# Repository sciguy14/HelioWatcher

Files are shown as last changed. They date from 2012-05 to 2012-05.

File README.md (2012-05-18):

HelioWatcher
============

The HelioWatcher is a Sun-Tracking Solar Analytics System developed by Jason Wright &amp; Jeremy Blum.
Learn more at www.heliowatcher.com

3D Prints
---------
Many of the mechanical parts for Actuating the HelioWatcher were 3D-Printed on a MakerBot Replicator.  In this folder, you will find all the design files (sketchup), STLs, and Replicator Dual G-Code Files.  You can also find them on the HelioWatcher Thingiverse Page: http://www.thingiverse.com/thing:22423

Code
----
This is the embedded code that runs on the ATmega-based MightyBoard MotherBoard that controls the HelioWatcher.  It was written in C using AVR Studio.

Datasheets
----------
These are Datasheets for the various electronic modules used in the HelioWatcher.

GRAPHING AND COLLECTION
-----------------------
These are scripts for performing automatic data acquisition from the Solar Panel

HelioWatcher Circuit
--------------------
These are the System-Level Circuit Diagrams from the HelioWatcher

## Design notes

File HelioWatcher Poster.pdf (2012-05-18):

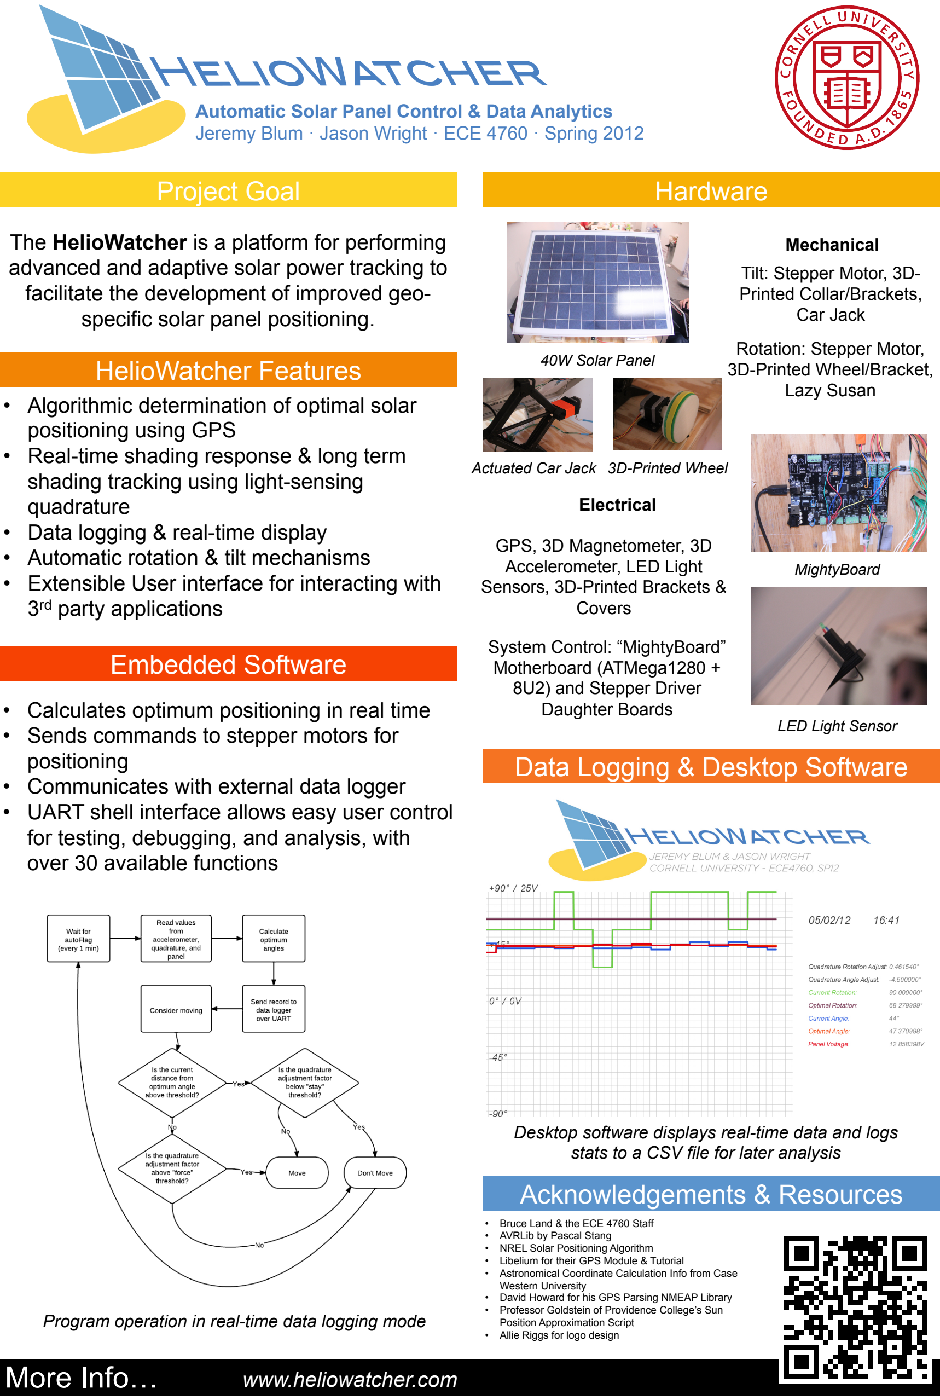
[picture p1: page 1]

### HelioWatcher Features

### Hardware

### Data Logging & Desktop Software

### Project Goal

### Acknowledgements & Resources

- Bruce Land & the ECE 4760 Staff
- AVRLib by Pascal Stang
- NREL Solar Positioning Algorithm
- Libelium for their GPS Module & Tutorial
- Astronomical Coordinate Calculation Info from Case Western University
- David Howard for his GPS Parsing NMEAP Library
- Professor Goldstein of Providence College’s Sun Position Approximation Script
- Allie Riggs for logo design

### Embedded Software

The HelioWatcher is a platform for performing advanced and adaptive solar power tracking to facilitate the development of improved geospecific solar panel positioning.

More Info… | www.heliowatcher.com

Automatic Solar Panel Control & Data Analytics Jeremy Blum · Jason Wright · ECE 4760 · Spring 2012

- Algorithmic determination of optimal solar positioning using GPS
- Real-time shading response & long term shading tracking using light-sensing quadrature
- Data logging & real-time display
- Automatic rotation & tilt mechanisms
- Extensible User interface for interacting with 3rd party applications

Mechanical

Electrical

Rotation: Stepper Motor,
3D-Printed Wheel/Bracket,
Lazy Susan

Tilt: Stepper Motor, 3D-Printed Collar/Brackets,
Car Jack

GPS, 3D Magnetometer, 3D
Accelerometer, LED Light
Sensors, 3D-Printed Brackets & Covers

System Control: “MightyBoard” Motherboard (ATMega1280 +
8U2) and Stepper Driver
Daughter Boards

40W Solar Panel

Desktop software displays real-time data and logs stats to a CSV file for later analysis

Actuated Car Jack 3D-Printed Wheel

MightyBoard

LED Light Sensor

- Calculates optimum positioning in real time
- Sends commands to stepper motors for positioning
- Communicates with external data logger
- UART shell interface allows easy user control for testing, debugging, and analysis, with over 30 available functions

Program operation in real-time data logging mode

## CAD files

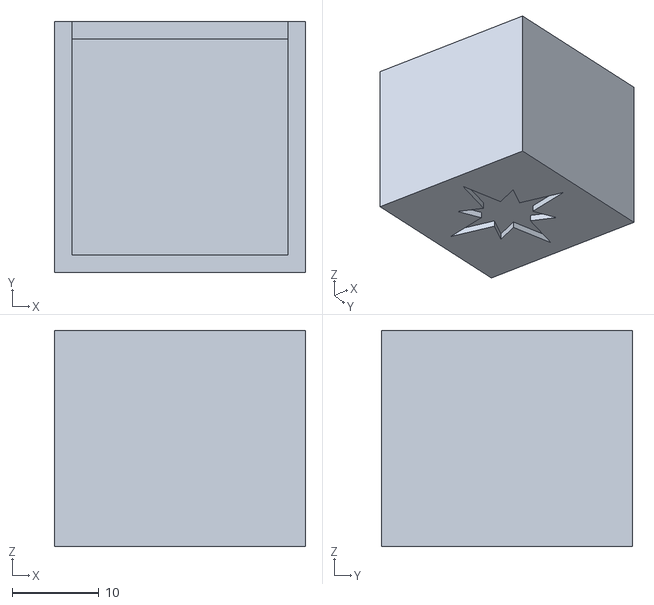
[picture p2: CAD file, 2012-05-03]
3D Prints/covers/mag_cover.stl
29.0 x 29.0 x 25.0

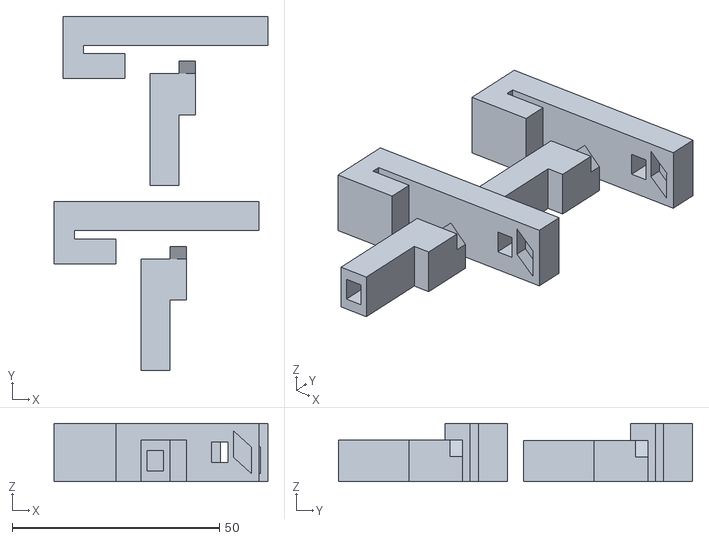
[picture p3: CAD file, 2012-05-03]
3D Prints/quadrature clips/clipTB.stl
51.6 x 85.5 x 14.1

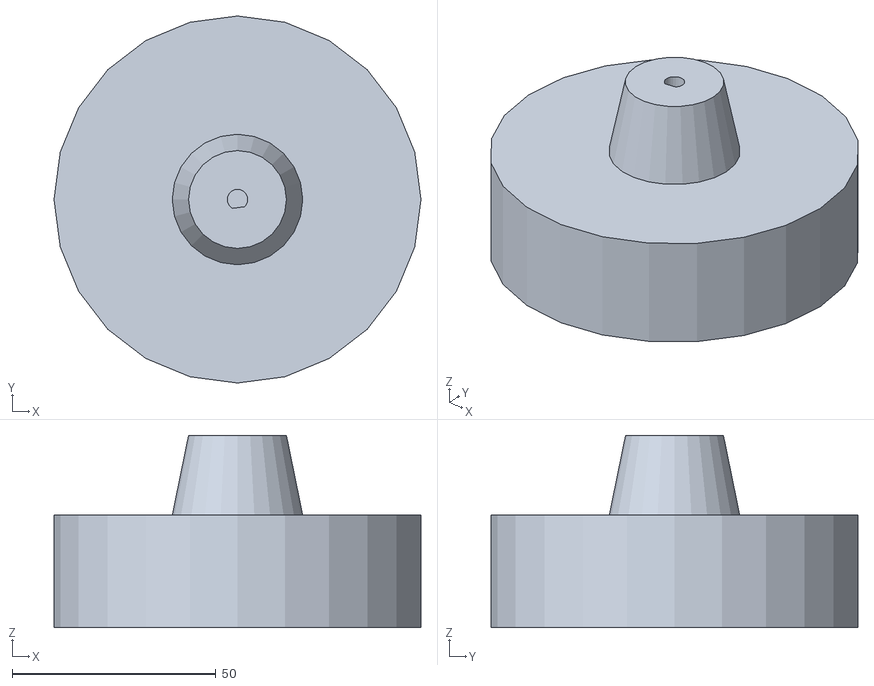
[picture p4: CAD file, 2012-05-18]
3D Prints/rotate/wheel.stl
90.0 x 90.0 x 47.2

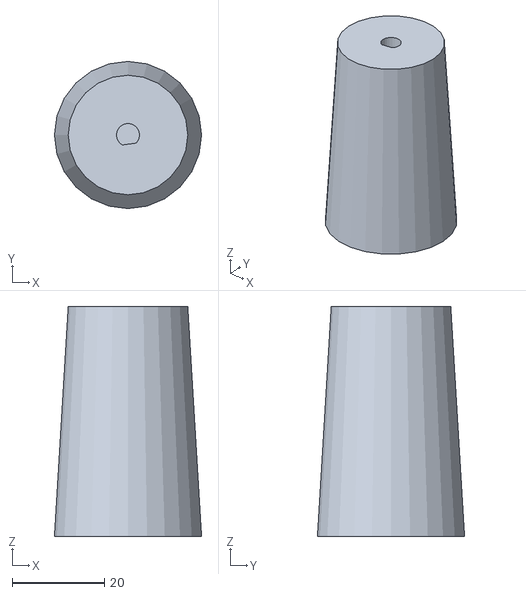
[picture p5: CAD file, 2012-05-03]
3D Prints/stepper jack bracket/collar.stl
32.0 x 32.0 x 50.0

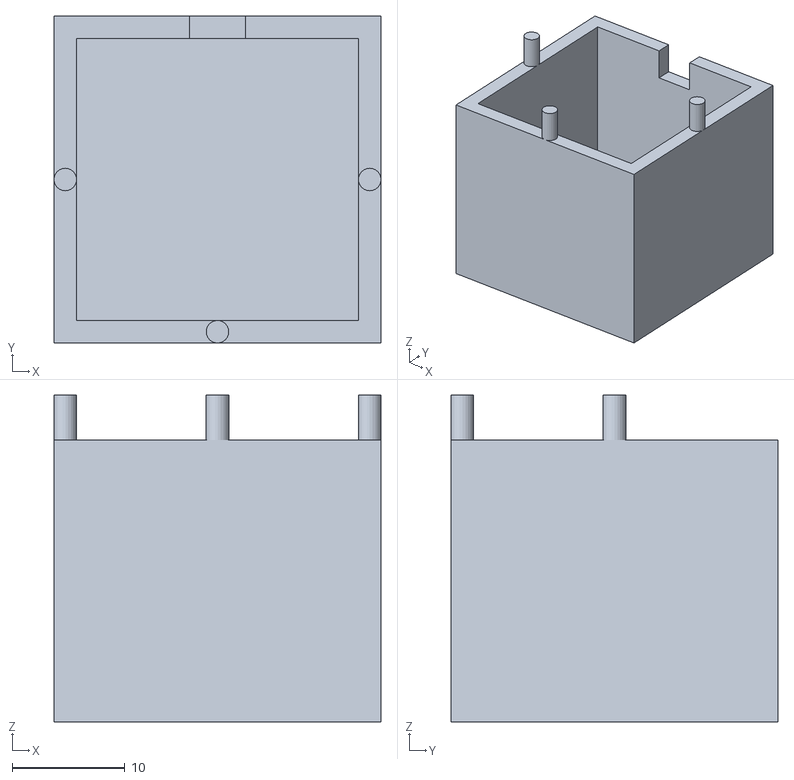
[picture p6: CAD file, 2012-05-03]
3D Prints/covers/ant_cover.stl
29.0 x 29.0 x 29.0

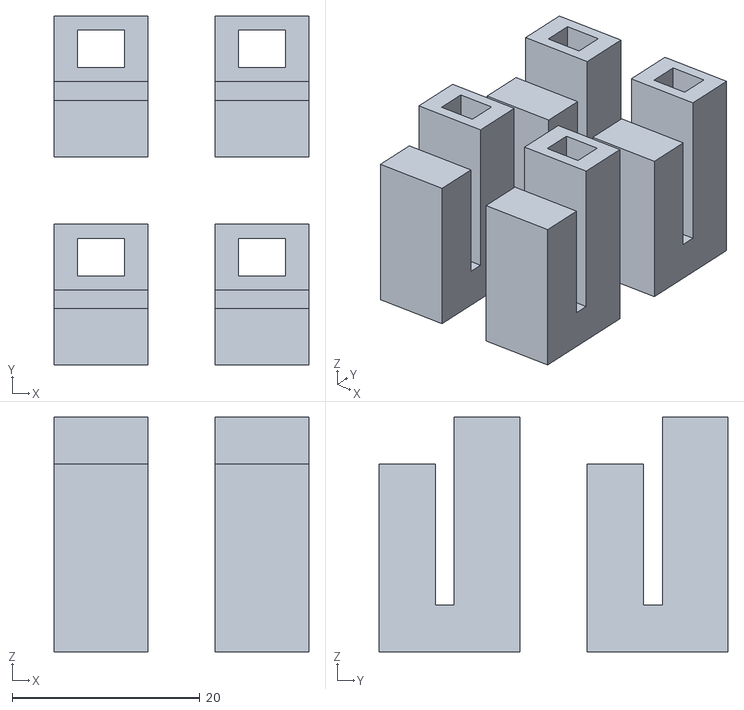
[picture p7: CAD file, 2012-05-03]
3D Prints/quadrature clips/clipLR.stl
27.2 x 37.2 x 25.0

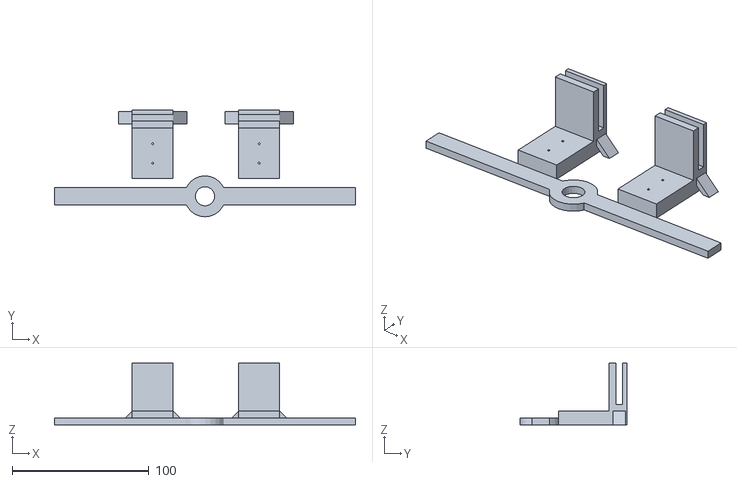
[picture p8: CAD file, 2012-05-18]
3D Prints/rotate/axis-holder.stl
220.0 x 77.9 x 45.0

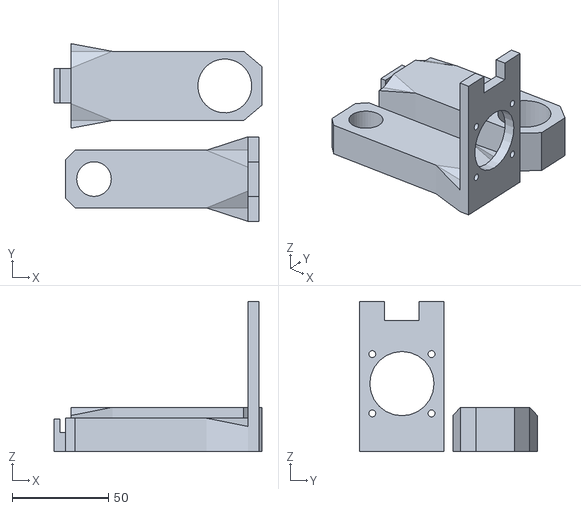
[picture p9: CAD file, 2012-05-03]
3D Prints/stepper jack bracket/jack_bracket.stl
108.2 x 92.5 x 78.2

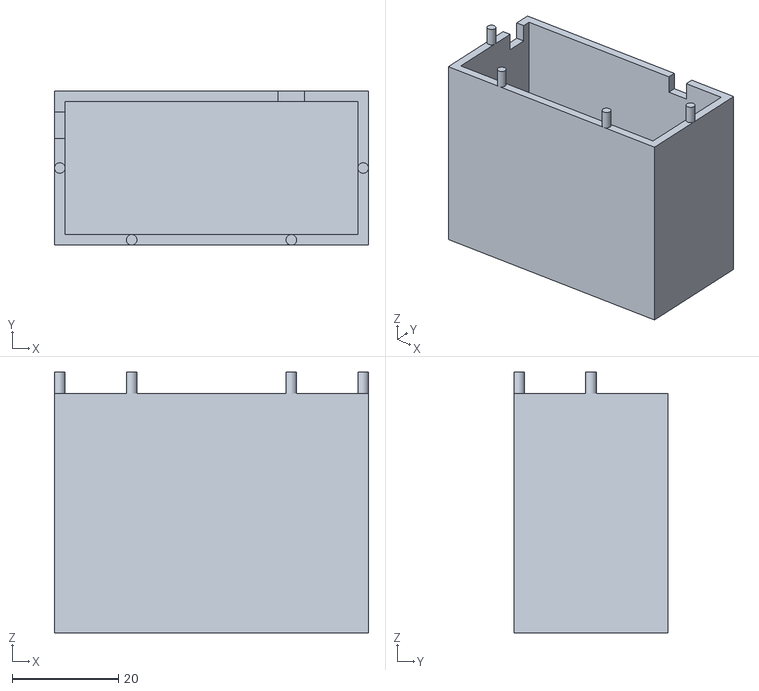
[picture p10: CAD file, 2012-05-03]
3D Prints/covers/gps-cover.stl
59.0 x 29.0 x 49.0

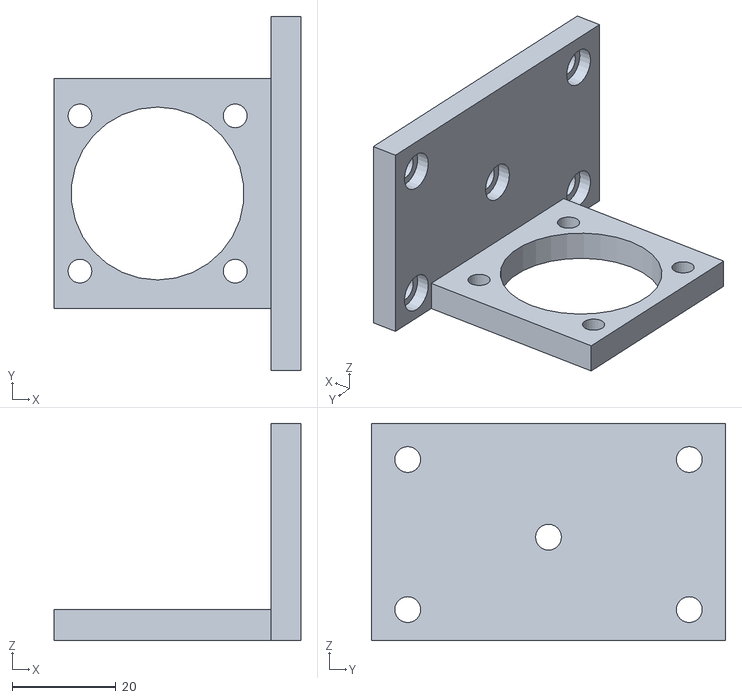
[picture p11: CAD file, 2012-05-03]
3D Prints/rotate/wheel_bracket.stl
47.7 x 68.4 x 42.0

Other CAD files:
3D Prints/covers/ant_cover.skp
3D Prints/covers/gps-cover.skp
3D Prints/covers/mag_cover.skp
3D Prints/quadrature clips/clipLR.skp
3D Prints/quadrature clips/clipTB.skp
3D Prints/rotate/axis-holder.skp
3D Prints/rotate/wheel.skp
3D Prints/rotate/wheel_bracket.skp
3D Prints/stepper jack bracket/collar.skp
3D Prints/stepper jack bracket/jack_bracket.skp

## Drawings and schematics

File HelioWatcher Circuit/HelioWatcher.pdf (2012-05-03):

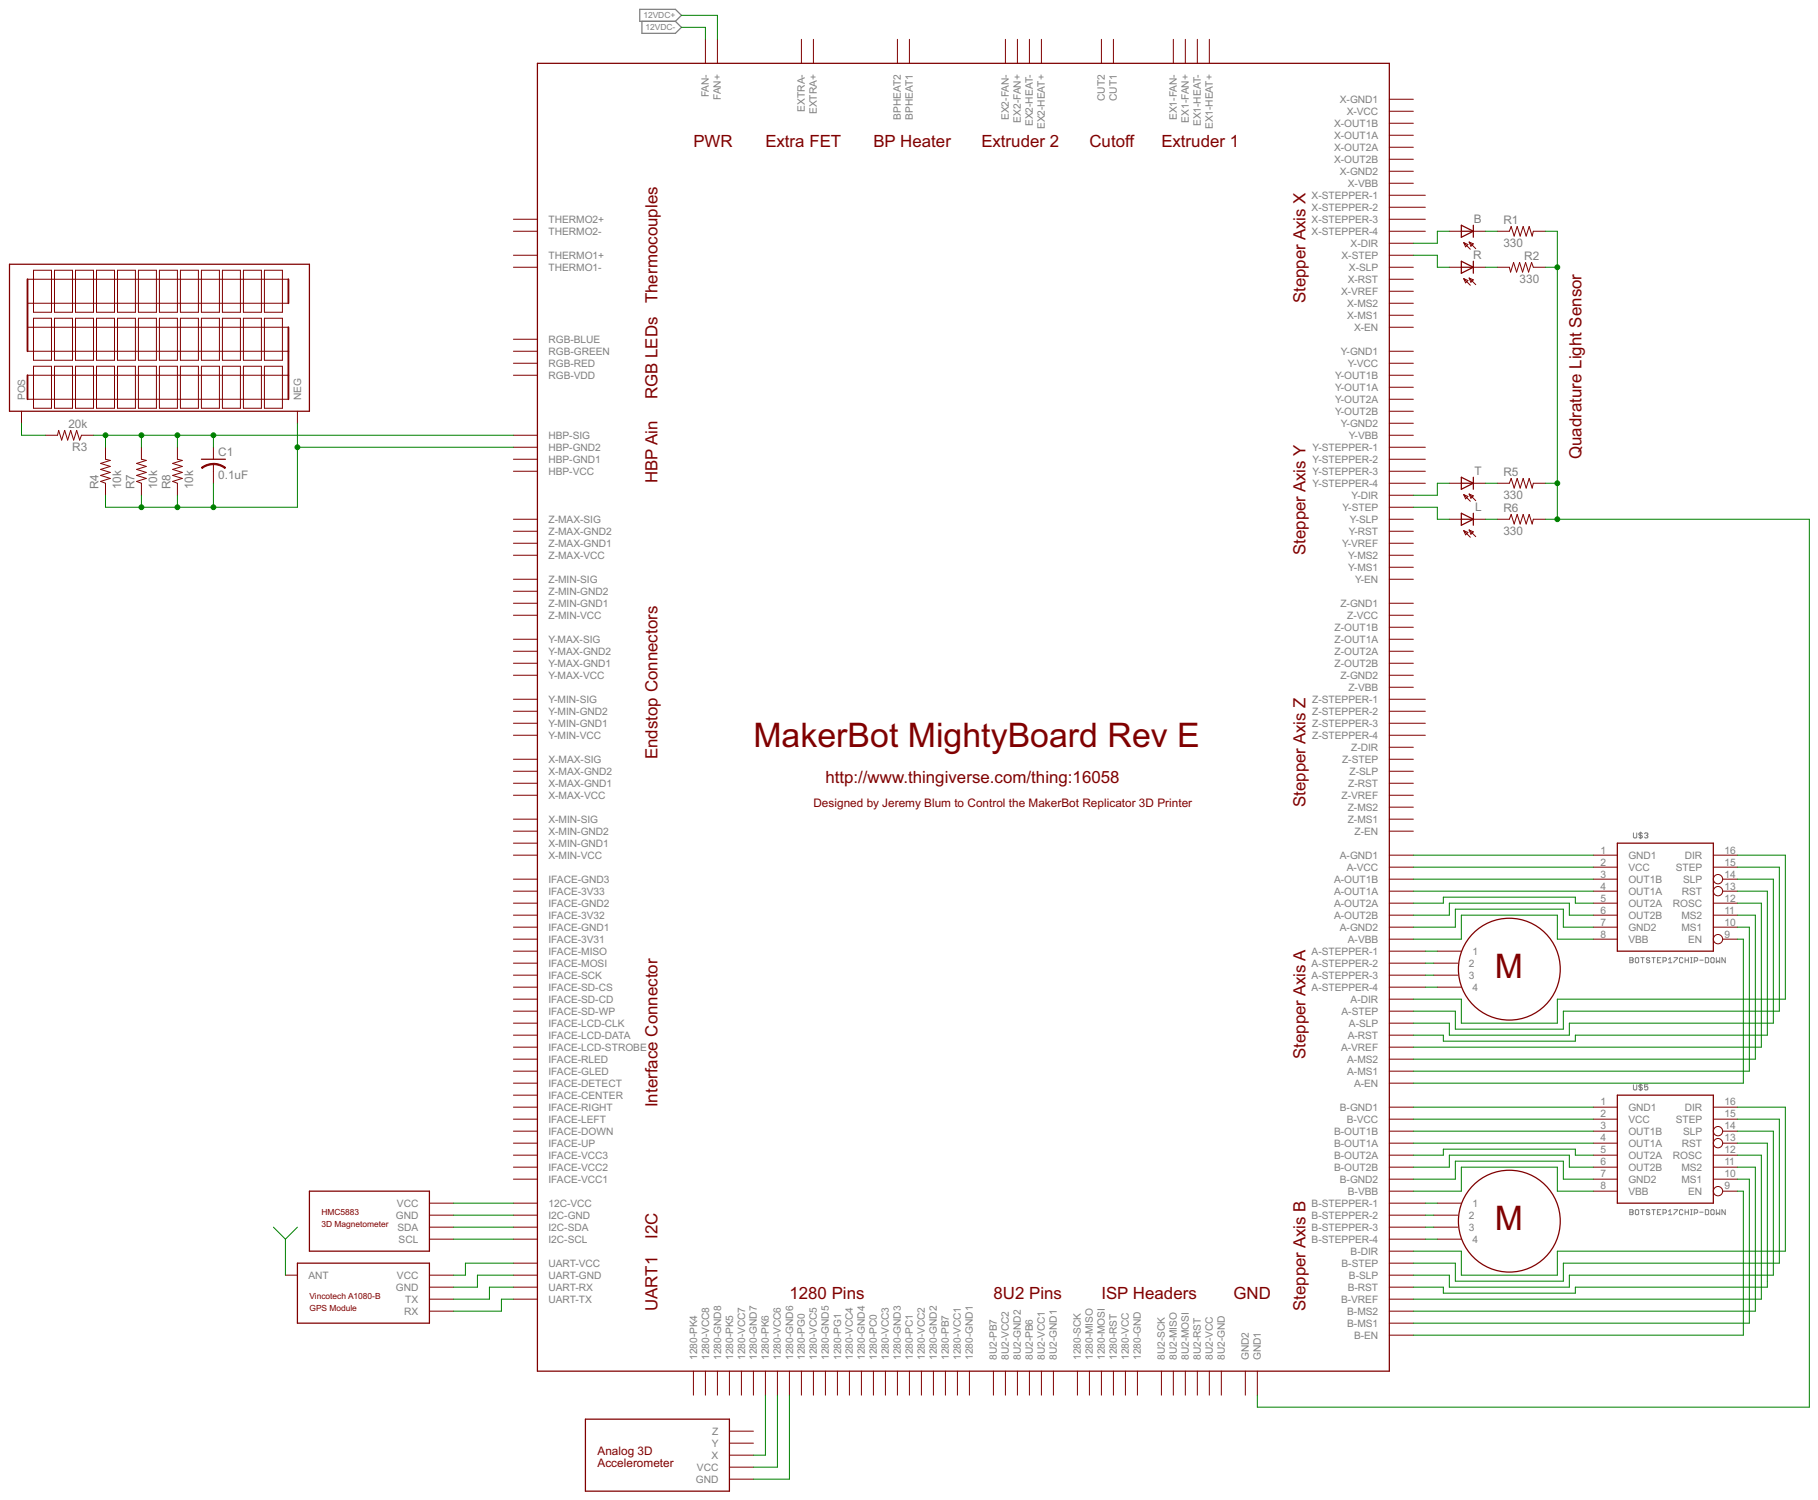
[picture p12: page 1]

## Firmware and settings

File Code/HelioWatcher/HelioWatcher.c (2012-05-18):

//*****************************************************************************
// HELIOWATCHER
// 
// ECE 4760 -- Designing with Microcontrollers
// Final Project, Spring 2012
// Jason Wright (jpw97) & Jeremy Blum (jeb373)		:	
// 
//*****************************************************************************

//*****************************************************************************
// Includes
//*****************************************************************************

//--Core AVR
#include <avr/io.h>		// include I/O definitions (port names, pin names, etc)
#include <avr/interrupt.h>	// include interrupt support
#include <avr/pgmspace.h>
#include <stdio.h>
#include <stdlib.h>
#include <string.h>
#include <inttypes.h>
#include <util/delay.h>
#include <ctype.h>
#include <math.h>

//--AVRlib
#include "AVRlib\global.h"		// include our global settings
#include "AVRlib\rprintf.h"	// include printf function library
//#include "AVRlib\a2d.h"		// include A/D converter function library
//#include "AVRlib\timerx8.h"		// include timer function library (timing, PWM, etc)
#include "AVRlib\vt100.h"		// include VT100 terminal support
#include "AVRlib\i2csw.h"		// include i2c software support (stepper voltage setting)
#include "i2cmaster\i2cmaster.h"
//#include "AVRlib\i2c.h"			// include i2c hardware support (Magnetometer)
#include "AVRlib\debug.h"		// include debug functions
#include "AVRlib\uart2.h"

//--Solar Positioning Algorithm
#include "spa.h"

//--ADC Necessities
#include <avr/sleep.h>
#include <avr/power.h>

//#include "integer.h"

//--Software Delay
#include <util/delay.h>

//--Serial Debugging
#define __ASSERT_USE_STDERR
#include <assert.h>
#include "uart_mod.h"

//--GPS NMEAP Library
#include "nmeap.h"

//*****************************************************************************
// Configuration & Initialization
//*****************************************************************************

//----- UART Config ---------------------------------------------------------
// UART file descriptor
// putchar and getchar are in uart.c
FILE uart_str_0 = FDEV_SETUP_STREAM(uart_putchar_0, uart_getchar_0, _FDEV_SETUP_RW); 
FILE uart_str_1 = FDEV_SETUP_STREAM(uart_putchar_1, uart_getchar_1, _FDEV_SETUP_RW); 


//----- I2C Config ---------------------------------------------------------
#define TARGET_ADDR	0x5E

#define MAG_ADDR 0x1E
#define HMC5883L_WRITE 0x3C // write address
#define HMC5883L_READ 0x3D // read address

// local data buffer
unsigned char localBuffer[] = "testing...testing...";
unsigned char localBufferLength = 0x20;

//----- System Config ---------------------------------------------------------
int autoMode = 0; //Toggles Automatic Mode
volatile int autoFlag = 0; //Set by the ISR every minute, if in auto mode.

//data log flag
int dataLog = 0;

//----- ADC Config ---------------------------------------------------------
//General
volatile int Ain, AinLow ;                      //raw A to D number
#define Vref1 1.104
volatile float Vref = Vref1;                    //Initialize Autoscaling Vref Choice

//Panel
volatile float panelVoltage;

//Quadrature Stuff
volatile float Uvoltage;                                 //scaled input voltage
volatile float Lvoltage;                                 //scaled input voltage
volatile float Rvoltage;                                 //scaled input voltage
volatile float Dvoltage;                                 //scaled input voltage
char v_string[10];                              //scaled input voltage string to print

//Cardinal direction to ADMUX
#define ADMUXU 0b01000000
#define ADMUXL 0b01000001
#define ADMUXD 0b01000100
#define ADMUXR 0b01000101

//----- Physical Config ---------------------------------------------------------
volatile float curr_accel;

float rot;

//Use these variables to hold the currently determined optimal values for the orientation of the solar panel
double opt_rot = 0; 		//rotation from due south in degrees
int opt_screw = 0;
double opt_angle = 45; 	//angle from flat in degrees

int curr_screw = 0;

//Buffers, in case they are needed
char accel_string[10];
char rot_string[10];

#define BASE_Z -180 //z-axis measurement without being on a screw
#define SCREW_THRESHOLD 20 //threshold to detect screw

//Custom screw thresholds -- can use this to calibrate for local magnetic interference.
#define USE_CUSTOM_SCREW_THRESHOLDS 1

//Be careful with this, make sure it's the same size as the number of screws you have.
//int custom_screw_thresholds[12] = {-115, -110, -100, -64, -40, -40, 100, 0, -80, -105, -120, -125};

//int screw values - we're gonna try doing hardcoded values.
int custom_screw_thresholds[24] = {-158, -350, -145, 14, -152, -276, -156, -295, -163, -90, -106, -124, -211, -388, 8, -461, -148, -227, -178, -313, -145, -27, -137, -322};

//screw theshold - +/- around the above defined values.
int custom_screw_error = 20;

#define SCREW_INITIAL_JUMP 40 //time for initial move, to get away from current screw
#define SCREW_BIG_JUMP 75 //not in use
#define SCREW_INCREMENT_TIME 20 //time for each move

#define MOVES_THRESHOLD 1 //Number of moves to make before considering stopping

//Raw Accelerometer values
int16_t raw_x = 0;
int16_t raw_y = 0;
int16_t raw_z = 0;

//angle vs accel calibration
//angle = m*accel + b
#define CALIB_M -0.4516
#define CALIB_B 220.56

#define MIN_ANGLE 30
#define MAX_ANGLE 52

#define OPT_ANGLE_MOVE_THRESHOLD 5 //how far away the optimum angle must be to move there
#define OPT_ANGLE_SAFETY_THRESHOLD 4 //max distance between curr angle and max/min angle to justify moving

#define QUAD_ANGLE_STAY_THRESHOLD 0 //how low the quad adjust value can be before moving
#define QUAD_ANGLE_MOVE_THRESHOLD 9999 //how high the quad adjust value must be to force moving

#define QUAD_ANGLE_INC_ADJUST 1000 //how much to adjust if quad forces a move

#define MIN_ROT -180
#define MAX_ROT 180

#define QUAD_ROT_STAY_THRESHOLD 0 //how low the quad adjust value can be before moving
#define QUAD_ROT_MOVE_THRESHOLD 9999 //how high the quad adjust value must be to force moving

#define NUM_SCREWS 24
#define ANGLE_BETWEEN_SCREWS 15

#define QUAD_ADJ_SCALE 1 //how much to multiple quad adjust values by to convert to angle

//these control motor speeds
#define JACK_DELAY_US 100
#define WHEEL_DELAY_US 3000

//settings for Torch Mode!
#define TORCH_SAFETY 10
#define TORCH_THRESHOLD 35
#define TORCH_ANGLE 5
#define TORCH_ROT 0.3

int i,j; //just in case

//----- RTC Initialization ---------------------------------------------------------
volatile int UTC_hour = 12;
volatile int UTC_min = 0;
volatile int UTC_sec = 55;
volatile int UTC_msec = 0;
int UTC_offset = -4;
int UTC_month = 5;
int UTC_day = 14;
int UTC_year = 2012;

//buffers used for a few different things
char fmtTimeString[7];
char fmtDateString[7];

//flags for proper RTC counting
volatile int incSec = 0;
volatile int incMin = 0;
volatile int incHr = 0;

//These are not in use, only relevant for NREL algorithm
float sr_hour = 5;	//Sun Rise Hour
float sr_min = 0;		//Sun Rise Minute
float sr_sec = 0;		//Sun Rise Seconds
float ss_hour = 20;	//Sun Set Hour
float ss_min = 0;		//Sun Set Minute
float ss_sec = 0;		//Sun Set Second

//----- I2C Function Headers ---------------------------------------------------------

void i2cTest(void);
void i2cSlaveReceiveService(u08 receiveDataLength, u08* receiveData);
u08 i2cSlaveTransmitService(u08 transmitDataLengthMax, u08* transmitData);
void i2cMasterSendDiag(u08 deviceAddr, u08 length, u08* data);
void testI2cMemory(void);
void showByte(u08 byte);


//----- GPS ---------------------------------------------------------

nmeap_gga_t g_gga;

char gpsbuff[60];

double lati = 42.441;
double longi = -76.485;
double alti = 202.5;
uint32_t utcTime;
int numSatellites;

//From the NMEAP library
char test_vector[] = {
"$GPGGA,123519,3929.946667,N,11946.086667,E,1,08,0.9,545.4,M,46.9,M,,*4A\r\n" /* good */
"$xyz,1234,asdfadfasdfasdfljsadfkjasdfk\r\n"                                  /* junk */
"$GPRMC,225446,A,4916.45,N,12311.12,W,000.5,054.7,191194,020.3,E*68\r\n"      /* good */
"$GPRMC,225446,A,4916.45,N,12311.12,W,000.5,054.7,191194,020.3,E*48\r\n"      /* checksum error */
};

char *pvec = test_vector;

//*****************************************************************************
// Functions -- General/Formatting
//*****************************************************************************

//string trimming
char *trim(char *s) {
    char *ptr;
    if (!s)
        return NULL;   // handle NULL string
    if (!*s)
        return s;      // handle empty string
    for (ptr = s + strlen(s) - 1; (ptr >= s) && isspace(*ptr); --ptr);
    ptr[1] = '\0';
    return s;
}

void updateTime(void)
{
	//Takes the value stored as utcTime (an int) and breaks it up into
	//component hour, minute, and second
	char timeString[11];
	sprintf(timeString, "%lu", utcTime);
	int timeStringLength = strlen(trim(timeString));

	if(dataLog==0)
	{
		fprintf(stdout, "time string: %s\r\n", timeString);
		fprintf(stdout, "time string length: %d\r\n", timeStringLength);
	}

	char minString[3];
	char secString[3];

	if(timeStringLength == 5)
	{
		char hourString[2];
		hourString[0] = timeString[0];
		UTC_hour = atoi(hourString);
		minString[0] = timeString[1];
		minString[1] = timeString[2];
		secString[0] = timeString[3];
		secString[1] = timeString[4];
	} 
	else
	{
		char hourString[3];
		hourString[0] = timeString[0];
		hourString[1] = timeString[1];
		UTC_hour = atoi(hourString);
		minString[0] = timeString[2];
		minString[1] = timeString[3];
		secString[0] = timeString[4];
		secString[1] = timeString[5];
	}

	
	UTC_min = atoi(minString);
	UTC_sec = atoi(secString);
}

void formatTime(void)
{
	//Writes UTC time components into a string.

	char hourBuff[3];
	char minBuff[3];
	char secBuff[3];

	int localHour = UTC_hour + UTC_offset;
	if (localHour < 0)
	{
		localHour += 24;
	}
	itoa(localHour, hourBuff, 10);
	itoa(UTC_min, minBuff, 10);
	itoa(UTC_sec, secBuff, 10);
	if (localHour < 10)
	{
		fmtTimeString[0] = '0';
		fmtTimeString[1] = hourBuff[0];
	}
	else
	{
		fmtTimeString[0] = hourBuff[0];
		fmtTimeString[1] = hourBuff[1];
	}
	
	if (UTC_min < 10)
	{
		fmtTimeString[2] = '0';
		fmtTimeString[3] = minBuff[0];
	}
	else
	{
		fmtTimeString[2] = minBuff[0];
		fmtTimeString[3] = minBuff[1];
	}

	if (UTC_sec < 10)
	{
		fmtTimeString[4] = '0';
		fmtTimeString[5] = secBuff[0];
	}
	else
	{
		fmtTimeString[4] = secBuff[0];
		fmtTimeString[5] = secBuff[1];
	}

}

void formatDate(void)
{
	//Writes UTC date components into a string.

	char yearBuff[4];
	char monthBuff[3];
	char dayBuff[3];

	itoa(UTC_year, yearBuff, 10);
	itoa(UTC_month, monthBuff, 10);
	itoa(UTC_day, dayBuff, 10);

	fmtDateString[4] = yearBuff[2];
	fmtDateString[5] = yearBuff[3];

	if (UTC_month < 10)
	{
		fmtDateString[0] = '0';
		fmtDateString[1] = monthBuff[0];
	}
	else
	{
		fmtDateString[0] = monthBuff[0];
		fmtDateString[1] = monthBuff[1];
	}

	if (UTC_day < 10)
	{
		fmtDateString[2] = '0';
		fmtDateString[3] = dayBuff[0];
	}
	else
	{
		fmtDateString[2] = dayBuff[0];
		fmtDateString[3] = dayBuff[1];
	}

}

//*****************************************************************************
// Functions -- GPS
//*****************************************************************************

/** simulate character by character IO */
int readchar() 
{
    int ch;
    if (*pvec == 0) {
        ch = -1;
    }
    else {
        ch = *pvec++;
    }
    return ch;
}



/** do something with the GGA data */
static void print_gga(nmeap_gga_t *gga)
{
    printf("found GPGGA message %.6f %.6f %.0f %lu %d %d %f %f\n",
            gga->latitude  ,
            gga->longitude, 
            gga->altitude , 
            gga->time     , 
            gga->satellites,
            gga->quality   ,
            gga->hdop      ,
            gga->geoid     
            );
}

//Getter functions from GGA sentence.

double gga_getLatitude(nmeap_gga_t *gga)
{
	return gga->latitude;
}

double gga_getLongitude(nmeap_gga_t *gga)
{
	return gga->longitude;
}

double gga_getAltitude(nmeap_gga_t *gga)
{
	return gga->altitude;
}

uint32_t gga_getUtcTime(nmeap_gga_t *gga)
{
	return gga->time;
}

int gga_getNumSatellites(nmeap_gga_t *gga)
{
	return gga->satellites;
}

/** called when a gpgga message is received and parsed */
static void gpgga_callout(nmeap_context_t *context,void *data,void *user_data)
{
    nmeap_gga_t *gga = (nmeap_gga_t *)data;
    
	if(dataLog == 0)
	{
	    printf("-------------callout\n");
	    print_gga(gga);
	}
}


/** do something with the RMC data */
static void print_rmc(nmeap_rmc_t *rmc)
{
    printf("found GPRMC Message %lu %c %.6f %.6f %f %f %lu %f\n",
            rmc->time,
            rmc->warn,
            rmc->latitude,
            rmc->longitude,
            rmc->speed,
            rmc->course,
            rmc->date,
            rmc->magvar
            );
}

/** called when a gprmc message is received and parsed */
static void gprmc_callout(nmeap_context_t *context,void *data,void *user_data)
{
    nmeap_rmc_t *rmc = (nmeap_rmc_t *)data;
    if(dataLog==0)
	{
    	printf("-------------callout\n");
    	print_rmc(rmc);
	}
}

static nmeap_context_t nmea;	   /* parser context */
static nmeap_gga_t     gga;		   /* this is where the data from GGA messages will show up */
static nmeap_rmc_t     rmc;		   /* this is where the data from RMC messages will show up */
static int             user_data; /* user can pass in anything. typically it will be a pointer to some user data */
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
int main(void)
{
	//init UARTs
	uart_init_0();
	uart_init_1();
	stdout = stdin = stderr = &uart_str_0;
	
	if(dataLog==0)
		fprintf(stdout,"Starting...\n\r");
	
	//set DDRs

	DDRG=0xff;
	DDRA=0xff;

	//Setting Stepper A Current to zero
	i2cInitA();
	u08 buf[1];      // a buffer can store 8 bytes 
	buf[0] = 0x00;   // hours = 0x19 in the first byte 
	i2cSendA(TARGET_ADDR, 0, 1, buf);

	//Setting Stepper B Current to zero
	i2cInitB();
	i2cSendB(TARGET_ADDR, 0, 1, buf);

	//Setup the Magnetometer
	i2c_init_HW();
	setupMag();

	PORTG |= 0b00000100; //disable jack stepper
	PORTA |= 0b00010000; //disable wheel stepper

	//init the A to D converter 

    ADMUX = 0b01000110; //sets voltage ref, right adjust result, sets most of MUX
    ADCSRA = ((1<<ADEN) | (1<<ADIE)) + 7 ; //enables the ADC, sets prescaler to 127, sets int enable
	ADCSRB |= 0b00001000; //one of the MUX bits is in here
	DIDR0 = ((1<<ADC5D) | (1<<ADC4D) | (1<<ADC1D) | (1<<ADC0D)); //disabling digital inputs
	DIDR2 = (1<<ADC15D);

    SMCR = (1<<SM0) ; // sleep -- choose ADC mode

	sleep_enable();

	//Set up 16-bit TIMER1 for 1mSec ticks for RTC
	TIMSK1 = 3;						//turn on timer 1 cmp match ISR and overflow ISR
	OCR1AH = 1999U >> 8; 			//sets OCR1A to 2000 ticks
	OCR1AL = 1999U & 0xff;
	TCCR1B = ((1<<CS11) | (1<<WGM12));	//clock prescalar to 8 and set to CTC mode
	
	sei(); //crank up them interrupts
	
	//Get Initial GPS data
	fscanf(&uart_str_1, "%s", gpsbuff);

	if(dataLog==0)
	{
		//Welcome
		fprintf(stdout, "Received GPS sentence: %s\n---\n", gpsbuff);

		fprintf(stdout, "*---Manual Operation---*\r\n");
		fprintf(stdout, "Welcome to HelioWatcher -- type help for a list of commands.\r\n");
	}
	else
	{
		//do some initialization for the data logger
		updateAccel();
		updateGPS();
		optimize2();
		autoMode = 1;

	}

	//Initialize variables used for user input
	char *spaceNum;
	int valNum ;
	float valFloat;
	char valStr[18];
	char input[20] ;
	char cmd_raw[18];
	char *cmd;
	
	while(1) {
		if(dataLog==0)
		{
			 //Print a prompt, and wait for input from the User.
			fprintf(stdout, ">") ;
	
			
			memset(input, 0, sizeof(input)); //Clear previous input
			fgets(input, 20, stdin); //Get the actual input
			spaceNum = strchr(input,' '); //Find space delimiter
			memset(valStr, 0, sizeof(valStr)); //Clear previous argument
	  		strncpy(valStr, spaceNum, strlen(spaceNum)); //Copy argument to valStr

			memset(cmd_raw, 0, sizeof(cmd_raw)); //Clear previous command
			strncpy(cmd_raw, input, strlen(input)-strlen(spaceNum)); //Copy command to cmd_raw
			cmd = trim(cmd_raw); //clean it

			//Convert to various formats
			valNum = atoi(trim(valStr));
			valFloat = atof(trim(valStr));

			//Big long pseudo-switch
			if (strcmp(cmd,"help") == 0)
			{
				fprintf(stdout, "Type a command (followed by an argument, if necessary) using the following syntax:\r\n");
				fprintf(stdout, "accel -- read accelerometer value (void)\r\n");
				fprintf(stdout, "angle -- go to angle (degrees)\r\n");
				fprintf(stdout, "angletoscrew -- convert angle to screw (degrees)\r\n");
				fprintf(stdout, "auto -- go into auto mode (void) **can't leave this\r\n");
				fprintf(stdout, "ccw -- go to nearest CCW screw (void)\r\n");
				fprintf(stdout, "compass -- get compass rotation (void) **DEPRECATED\r\n");
				fprintf(stdout, "cw -- go to nearest CW screw (void)\r\n");  
				fprintf(stdout, "data -- go into data logging mode (void) **can't leave this\r\n");
				fprintf(stdout, "date -- display the current date (void)\r\n");
				fprintf(stdout, "down -- move down (ms)\r\n");
				fprintf(stdout, "gotoopt -- move to optimal position (void) **must run opt first\r\n");
				fprintf(stdout, "gps -- read GPS values (void)\r\n");
				fprintf(stdout, "help -- list HelioWatcher shell functions\r\n");
				fprintf(stdout, "left -- move left (ms)\r\n");
				fprintf(stdout, "opt -- get optimal positioning info based on current GPS data (void) **must run gps first\r\n");
				fprintf(stdout, "panel -- display the panel voltage (void)\r\n");
				fprintf(stdout, "quad -- view quadrature values (void)\r\n");
				fprintf(stdout, "record -- print string that would be sent to data logger (void)\r\n");
				fprintf(stdout, "right -- move right (ms)\r\n");
				fprintf(stdout, "rot -- go to rot (degrees) **DEPRECATED\r\n");
				fprintf(stdout, "screw -- go to arbitrary screw (screw num)\r\n");
				fprintf(stdout, "setday -- set UTC day (int)\r\n");
				fprintf(stdout, "sethour -- set UTC hour (int)\r\n");
				fprintf(stdout, "setmin -- set UTC min (int)\r\n");
				fprintf(stdout, "setmonth -- set UTC month (int)\r\n");
				fprintf(stdout, "setsec -- set UTC sec (int)\r\n");
				fprintf(stdout, "setyear -- set UTC year (int)\r\n");
				fprintf(stdout, "time -- display the current time (void)\r\n");
				fprintf(stdout, "torch -- orient based on quadrature demo (sensitivity 0-100) **can't leave this\r\n");
				fprintf(stdout, "up -- move up (ms)\r\n");					
			}
			else if (strcmp(cmd,"opt") == 0)
			{
				optimize2();
			}
			else if (strcmp(cmd,"quad") == 0)
			{
				updateQuad();

				//print values
				dtostrf(Uvoltage, 6, 3, v_string);    
				fprintf(stdout, "U voltage: %s\r\n", v_string); 
				dtostrf(Lvoltage, 6, 3, v_string);    
				fprintf(stdout, "L voltage: %s\r\n", v_string); 
				dtostrf(Rvoltage, 6, 3, v_string);    
				fprintf(stdout, "R voltage: %s\r\n", v_string);
				dtostrf(Dvoltage, 6, 3, v_string);    
				fprintf(stdout, "D voltage: %s\r\n", v_string);

			}
			else if (strcmp(cmd,"torch") == 0)
			{
				//Torch mode -- Hold up a "torch" to the panel to move it in real time.
				int UDaxis;
				int UDchange;
				int LRaxis;
				int LRchange;
				int currAngle;

				while(1)
				{

					//Update all the values, and print them
					updateAccel();
					currAngle = accelToAngle(curr_accel);
					fprintf(stdout, "currAngle %u\r\n", currAngle);

					updateQuad();
					UDaxis = Uvoltage-Dvoltage;
					UDchange = abs(UDaxis)*valNum;

					dtostrf(UDaxis, 6, 3, v_string);    
					fprintf(stdout, "UD axis: %s\r\n", v_string);

					LRaxis = Lvoltage-Rvoltage;
					LRchange = abs(LRaxis)*valNum;

					dtostrf(LRaxis, 6, 3, v_string);    
					fprintf(stdout, "LR axis: %s\r\n", v_string);

					//Change angle
					if(abs(UDaxis)>TORCH_THRESHOLD)
					{
						if (UDaxis>0)
						{
							if(currAngle>MIN_ANGLE+TORCH_SAFETY)
								goDown(UDchange*TORCH_ANGLE);
						}
						else
						{
							if(currAngle<MAX_ANGLE-TORCH_SAFETY)
								goUp(UDchange*TORCH_ANGLE);
						}
					}

					//Change rotation
					if(abs(LRaxis)>TORCH_THRESHOLD)
					{
						if(LRaxis>0)
						{
							goLeft(LRchange*TORCH_ROT);
						}
						else
						{
							goRight(LRchange*TORCH_ROT);
						}
					}
				}
			}
			else if (strcmp(cmd,"angletoscrew") == 0)
			{
				int convertedScrew = rotToNearestScrew(valFloat);
				fprintf(stdout, "screw is %u\r\n", convertedScrew);
			}
			else if (strcmp(cmd,"screw") == 0)
			{
				goToScrew(valNum);
			}
			else if (strcmp(cmd,"cw") == 0)
			{
				goToScrewCW();
			}
			else if (strcmp(cmd,"ccw") == 0)
			{
				goToScrewCCW();
			}
			else if (strcmp(cmd,"compass") == 0)
			{
				updateRot(); //updates rot
				curr_screw = rotToNearestScrew(rot);
				fprintf(stdout, "Nearest screw: %d\n\r", curr_screw);
			}
			else if (strcmp(cmd,"gotoopt") == 0)
			{
				//Moves to optimum values of angle and rot, if possible.
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

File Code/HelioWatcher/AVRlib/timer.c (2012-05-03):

/*! \file timer.c \brief System Timer function library. */
//*****************************************************************************
//
// File Name	: 'timer.c'
// Title		: System Timer function library
// Author		: Pascal Stang - Copyright (C) 2000-2002
// Created		: 11/22/2000
// Revised		: 07/09/2003
// Version		: 1.1
// Target MCU	: Atmel AVR Series
// Editor Tabs	: 4
//
// This code is distributed under the GNU Public License
//		which can be found at http://www.gnu.org/licenses/gpl.txt
//
//*****************************************************************************

#include <avr/io.h>
#include <avr/interrupt.h>
#include <avr/pgmspace.h>
#include <avr/sleep.h>

#include "global.h"
#include "timer.h"

#include "rprintf.h"

// Program ROM constants
// the prescale division values stored in order of timer control register index
// STOP, CLK, CLK/8, CLK/64, CLK/256, CLK/1024
unsigned short __attribute__ ((progmem)) TimerPrescaleFactor[] = {0,1,8,64,256,1024};
// the prescale division values stored in order of timer control register index
// STOP, CLK, CLK/8, CLK/32, CLK/64, CLK/128, CLK/256, CLK/1024
unsigned short __attribute__ ((progmem)) TimerRTCPrescaleFactor[] = {0,1,8,32,64,128,256,1024};

// Global variables
// time registers
volatile unsigned long TimerPauseReg;
volatile unsigned long Timer0Reg0;
volatile unsigned long Timer2Reg0;

typedef void (*voidFuncPtr)(void);
volatile static voidFuncPtr TimerIntFunc[TIMER_NUM_INTERRUPTS];

// delay for a minimum of <us> microseconds 
// the time resolution is dependent on the time the loop takes 
// e.g. with 4Mhz and 5 cycles per loop, the resolution is 1.25 us 
void delay_us(unsigned short time_us) 
{
	unsigned short delay_loops;
	register unsigned short i;

	delay_loops = (time_us+3)/5*CYCLES_PER_US; // +3 for rounding up (dirty) 

	// one loop takes 5 cpu cycles 
	for (i=0; i < delay_loops; i++) {};
}
/*
void delay_ms(unsigned char time_ms)
{
	unsigned short delay_count = F_CPU / 4000;

	unsigned short cnt;
	asm volatile ("\n"
                  "L_dl1%=:\n\t"
                  "mov %A0, %A2\n\t"
                  "mov %B0, %B2\n"
                  "L_dl2%=:\n\t"
                  "sbiw %A0, 1\n\t"
                  "brne L_dl2%=\n\t"
                  "dec %1\n\t" "brne L_dl1%=\n\t":"=&w" (cnt)
                  :"r"(time_ms), "r"((unsigned short) (delay_count))
	);
}
*/
void timerInit(void)
{
	u08 intNum;
	// detach all user functions from interrupts
	for(intNum=0; intNum<TIMER_NUM_INTERRUPTS; intNum++)
		timerDetach(intNum);

	// initialize all timers
	timer0Init();
	timer1Init();
	#ifdef TCNT2	// support timer2 only if it exists
	timer2Init();
	#endif
	// enable interrupts
	sei();
}

void timer0Init()
{
	// initialize timer 0
	timer0SetPrescaler( TIMER0PRESCALE );	// set prescaler
	outb(TCNT0, 0);							// reset TCNT0
	sbi(TIMSK0, TOIE0);						// enable TCNT0 overflow interrupt

	timer0ClearOverflowCount();				// initialize time registers
}

void timer1Init(void)
{
	// initialize timer 1
	timer1SetPrescaler( TIMER1PRESCALE );	// set prescaler
	outb(TCNT1H, 0);						// reset TCNT1
	outb(TCNT1L, 0);
	sbi(TIMSK1, TOIE1);						// enable TCNT1 overflow
}

#ifdef TCNT2	// support timer2 only if it exists
void timer2Init(void)
{
	// initialize timer 2
	timer2SetPrescaler( TIMER2PRESCALE );	// set prescaler
	outb(TCNT2, 0);							// reset TCNT2
	sbi(TIMSK2, TOIE2);						// enable TCNT2 overflow

	timer2ClearOverflowCount();				// initialize time registers
}
#endif

void timer0SetPrescaler(u08 prescale)
{
	// set prescaler on timer 0
	outb(TCCR0, (inb(TCCR0) & ~TIMER_PRESCALE_MASK) | prescale);
}

void timer1SetPrescaler(u08 prescale)
{
	// set prescaler on timer 1
	outb(TCCR1B, (inb(TCCR1B) & ~TIMER_PRESCALE_MASK) | prescale);
}

#ifdef TCNT2	// support timer2 only if it exists
void timer2SetPrescaler(u08 prescale)
{
	// set prescaler on timer 2
	outb(TCCR2, (inb(TCCR2) & ~TIMER_PRESCALE_MASK) | prescale);
}
#endif

u16 timer0GetPrescaler(void)
{
	// get the current prescaler setting
	return (pgm_read_word(TimerPrescaleFactor+(inb(TCCR0) & TIMER_PRESCALE_MASK)));
}

u16 timer1GetPrescaler(void)
{
	// get the current prescaler setting
	return (pgm_read_word(TimerPrescaleFactor+(inb(TCCR1B) & TIMER_PRESCALE_MASK)));
}

#ifdef TCNT2	// support timer2 only if it exists
u16 timer2GetPrescaler(void)
{
	//TODO: can we assume for all 3-timer AVR processors,
	// that timer2 is the RTC timer?

	// get the current prescaler setting
	return (pgm_read_word(TimerRTCPrescaleFactor+(inb(TCCR2) & TIMER_PRESCALE_MASK)));
}
#endif

void timerAttach(u08 interruptNum, void (*userFunc)(void) )
{
	// make sure the interrupt number is within bounds
	if(interruptNum < TIMER_NUM_INTERRUPTS)
	{
		// set the interrupt function to run
		// the supplied user's function
		TimerIntFunc[interruptNum] = userFunc;
	}
}

void timerDetach(u08 interruptNum)
{
	// make sure the interrupt number is within bounds
	if(interruptNum < TIMER_NUM_INTERRUPTS)
	{
		// set the interrupt function to run nothing
		TimerIntFunc[interruptNum] = 0;
	}
}
/*
u32 timerMsToTics(u16 ms)
{
	// calculate the prescaler division rate
	u16 prescaleDiv = 1<<(pgm_read_byte(TimerPrescaleFactor+inb(TCCR0)));
	// calculate the number of timer tics in x milliseconds
	return (ms*(F_CPU/(prescaleDiv*256)))/1000;
}

u16 timerTicsToMs(u32 tics)
{
	// calculate the prescaler division rate
	u16 prescaleDiv = 1<<(pgm_read_byte(TimerPrescaleFactor+inb(TCCR0)));
	// calculate the number of milliseconds in x timer tics
	return (tics*1000*(prescaleDiv*256))/F_CPU;
}
*/
void timerPause(unsigned short pause_ms)
{
	// pauses for exactly <pause_ms> number of milliseconds
	u08 timerThres;
	u32 ticRateHz;
	u32 pause;

	// capture current pause timer value
	timerThres = inb(TCNT0);
	// reset pause timer overflow count
	TimerPauseReg = 0;
	// calculate delay for [pause_ms] milliseconds
	// prescaler division = 1<<(pgm_read_byte(TimerPrescaleFactor+inb(TCCR0)))
	ticRateHz = F_CPU/timer0GetPrescaler();
	// precision management
	// prevent overflow and precision underflow
	//	-could add more conditions to improve accuracy
	if( ((ticRateHz < 429497) && (pause_ms <= 10000)) )
		pause = (pause_ms*ticRateHz)/1000;
	else
		pause = pause_ms*(ticRateHz/1000);

	// loop until time expires
	while( ((TimerPauseReg<<8) | inb(TCNT0)) < (pause+timerThres) )
	{
		if( TimerPauseReg < (pause>>8));
		{
			// save power by idling the processor
			set_sleep_mode(SLEEP_MODE_IDLE);
			sleep_mode();
		}
	}

	/* old inaccurate code, for reference
	
	// calculate delay for [pause_ms] milliseconds
	u16 prescaleDiv = 1<<(pgm_read_byte(TimerPrescaleFactor+inb(TCCR0)));
	u32 pause = (pause_ms*(F_CPU/(prescaleDiv*256)))/1000;
	
	TimerPauseReg = 0;
	while(TimerPauseReg < pause);

	*/
}

void timer0ClearOverflowCount(void)
{
	// clear the timer overflow counter registers
	Timer0Reg0 = 0;	// initialize time registers
}
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
